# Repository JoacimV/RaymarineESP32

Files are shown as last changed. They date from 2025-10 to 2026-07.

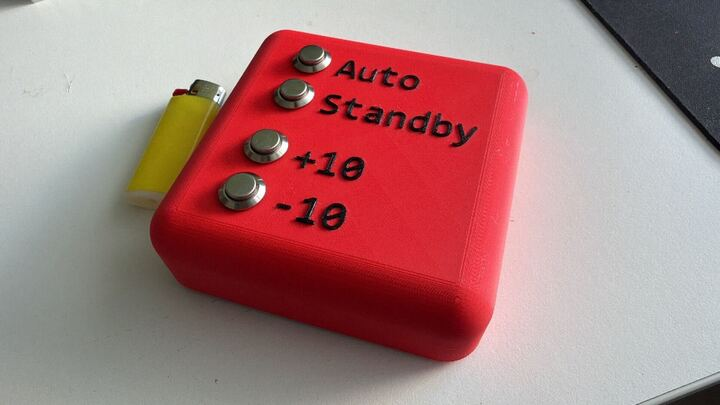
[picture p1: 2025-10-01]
resources/case.png

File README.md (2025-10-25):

### Intro
billede

I wanted an extra way to control my boat's Raymarine autopilot, so I built a simple remote control using an ESP32, MCP2515 CAN Bus module, and some buttons. The remote sends commands to the autopilot over the NMEA2000 network.

The remotes capabilities are basic, but it gets the job done. It has buttons for AUTO, STANDBY, +10 degrees, and -10 degrees. The remote connects to the NMEA2000 network using a MCP2515 CAN Bus module.

This remote costs around 15€ to build, which is significantly cheaper than buying a commercial remote (730€ as of writing this).

The remote connects to the NMEA2000 network, so you need to connect your SeaTalkNG network to your NMEA2000 network, with a NMEA2000 adapter cable.

It currently only works with Raymarine autopilots that support the NMEA2000 protocol, such as the EV-100 and EV-200 series. (I have tested it with EV-100).

### Hardware
- ESP32 + Expansion board - [Amazon affiliate Link](https://amzn.to/46IAd6L)

- MCP2515 CAN Bus Module - [Amazon affiliate Link](https://amzn.to/4nZz4yW)

- Jumper wires [Amazon affiliate Link](https://amzn.to/4pUqzHe)
- DC Cable [Amazon affiliate Link](https://amzn.to/4nsR4Sa)
- NMEA2000 Cable (Cut the female port off) - [Amazon affiliate Link](https://amzn.to/46G0wfn)
- Buttons - [Amazon affiliate Link](https://amzn.to/3IAz6OH)
- Diode WS2812B [Amazon affiliate Link](https://amzn.to/4hwteD4)
- Active Piezo Buzzer [Amazon affiliate Link](https://amzn.to/42XU9lj)

### 3D Printed Case
I designed the case using blender and printed it with BambuLab PLA Matte. You can find the STL files in the `case` directory of this repository.

### Pins

| ESP32 Pin | MCP2515 Pin | Description |
| --- | --- | --- |
| GPIO5 | CS | Chip Select |
| GPIO18 | SCK | Serial Clock |
| GPIO19 | SO | Master In Slave Out |
| GPIO23 | SI | Master Out Slave In |

To power the MCP2515 module, connect the VCC and GND pins to a 5V power on the expansion board.
NMEA2000 power goes to the expansion board through a type b connector.

NMEA white and blue wire go to the MCP2515 module, blue wire to CANL and white wire to CANH.

Wiring for buttons:

| Button  | ESP32 Pin | Description  |
| --- | --- | --- |
| AUTO | GPIO13 | Button Input |
| STANDBY | GPIO12 | Button Input |
| +10 | GPIO14 | Button Input |
| -10 | GPIO26 | Button Input |

Wiring for buzzer:

| Buzzer Pin | ESP32 Pin | Description  |
| --- | --- | --- |
| + | GPIO4 | Buzzer Input |
| GND | GND | Ground |

### Software
This project is built using [PlatformIO](https://platformio.org/).

The raymarine pilot commands are greatly inspired by [this project](https://github.com/matztam/raymarine-evo-pilot-remote).

### Running the Code

## On ESP32
1. Install PlatformIO IDE in Visual Studio Code.
2. Clone this repository to your local machine.
3. Open the project in Visual Studio Code.
4. Connect your ESP32 to your computer via USB.
5. Select the correct board and port in PlatformIO.
6. Click the "Upload" button in PlatformIO to compile and upload the code to your ESP32.

## On your PC
1. Install PlatformIO IDE in Visual Studio Code.
2. Clone this repository to your local machine.
3. Open the project in Visual Studio Code.
4. Open PlatformIO and hit the Build button.
   
### Disclaimer
This project is provided as-is without any warranties. Use it at your own risk. The author is not responsible for any damage or issues that may arise from using this project.

### Libraries
- Timo Lappalainen NMEA2000 library and MCP library: [GitHub Link](https://github.com/ttlappalainen)
- Seeed-Studio CAN library: [GitHub Link](https://github.com/Seeed-Studio/Seeed_Arduino_CAN)

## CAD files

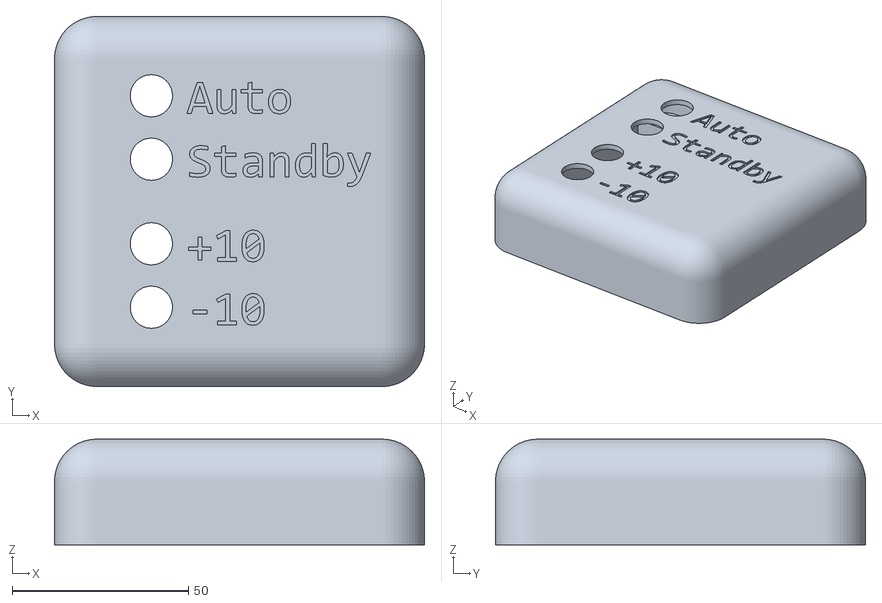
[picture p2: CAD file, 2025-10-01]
resources/case.stl
105.0 x 105.0 x 30.0

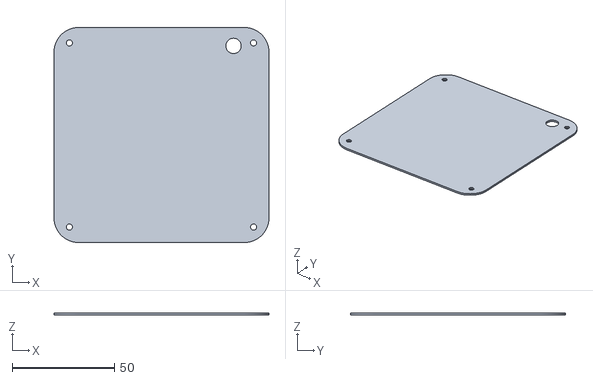
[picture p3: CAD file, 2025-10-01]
resources/lid.stl
105.0 x 105.0 x 1.00

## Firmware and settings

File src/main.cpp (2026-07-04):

#include <Arduino.h>
#include "AutopilotInterface.h"
#include "RaymarinePilot.h"
#include "MessageHandler.h"
#include "BuzzerInterface.h"
#include "PiezoActiveBuzzer.h"
#include "Button2.h"

// Create button instances
Button2 on(14);       // Pin 14 - Auto Mode
Button2 plusTen(12);  // Pin 12 - Starboard 10°
Button2 minusTen(13); // Pin 13 - Port 10°

// Buzzer instance (using interface for flexibility)
BuzzerInterface *buzzer = new PiezoActiveBuzzer(27);

// Global pilot instance (will be initialized in setup())
AutopilotInterface *pilot = nullptr;

void pilotStateUpdateHandler(AutopilotInterface::PilotState state)
{
  if (pilot != nullptr)
  {
    pilot->setObservedState(state);
  }
}

// Handler functions
void onHandler(Button2 &btn)
{
  buzzer->beep();
  AutopilotInterface::PilotState state = pilot->getState();

  // Toggle based on latest bus state; unknown defaults to AUTO.
  if (state == AutopilotInterface::STATE_AUTO)
  {
    pilot->setMode(AutopilotInterface::MODE_STANDBY);
  }
  else
  {
    pilot->setMode(AutopilotInterface::MODE_AUTO);
  }
}

void plusTenHandler(Button2 &btn)
{
  buzzer->beep();
  pilot->turn(AutopilotInterface::TURN_RIGHT_TEN);
}

void minusTenHandler(Button2 &btn)
{
  buzzer->beep();
  pilot->turn(AutopilotInterface::TURN_LEFT_TEN);
}

// Setup function - now AFTER handler definitions
void setup()
{
  Serial.begin(115200);
  Serial.println("Starting Raymarine ESP32 Remote...");

  // Initialize buzzer
  buzzer->begin();

  pilot = new RaymarinePilot();
  if (pilot->isReady())
  {
    Serial.println("✅ Raymarine ESP32 Remote Ready!");
  }
  else
  {
    Serial.println("❌ NMEA2000 failed to initialize");
  }
  MessageHandler::SetPilotStateUpdateCallback(pilotStateUpdateHandler);

  // Setup buttons with handlers
  on.setTapHandler(onHandler);
  plusTen.setTapHandler(plusTenHandler);
  minusTen.setTapHandler(minusTenHandler);
}

void loop()
{
  on.loop();
  plusTen.loop();
  minusTen.loop();
  pilot->update();
  // Small delay to save CPU cycles
  // delay(40);
}

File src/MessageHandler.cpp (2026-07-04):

#include "MessageHandler.h"
#include <Arduino.h>

MessageHandler::PilotStateUpdateCallback MessageHandler::StateUpdateCallback = nullptr;

// Handle incoming NMEA2000 messages
void MessageHandler::HandleNMEA2000Msg(const tN2kMsg &N2kMsg) {
    switch (N2kMsg.PGN) {
        case 65379L:  // Autopilot status
            ParseAutopilotStatus(N2kMsg);
            break;
        // Add more PGN handlers here as needed
        default:
            // Uncomment for debugging unknown messages
            // Serial.print("📡 Unknown PGN: ");
            // Serial.println(N2kMsg.PGN);
            break;
    }
}

void MessageHandler::SetPilotStateUpdateCallback(PilotStateUpdateCallback callback) {
    StateUpdateCallback = callback;
}

// Parse autopilot status message (PGN 65379)
void MessageHandler::ParseAutopilotStatus(const tN2kMsg &N2kMsg) {
    int Index = 2;
    unsigned char Mode = N2kMsg.GetByte(Index);
    unsigned char Submode = N2kMsg.GetByte(Index);

    Serial.print("🚢 PILOT: ");
    if (Mode == 0x00 && Submode == 0x00) {
        if (StateUpdateCallback != nullptr) {
            StateUpdateCallback(AutopilotInterface::STATE_STANDBY);
        }
        Serial.println("STANDBY");
    }
    else if (Mode == 0x40 && Submode == 0x00) {
        if (StateUpdateCallback != nullptr) {
            StateUpdateCallback(AutopilotInterface::STATE_AUTO);
        }
        Serial.println("AUTO");
    }
    else {
        if (StateUpdateCallback != nullptr) {
            StateUpdateCallback(AutopilotInterface::STATE_UNKNOWN);
        }
        Serial.print("Mode=0x");
        Serial.print(Mode, HEX);
        Serial.print(" Sub=0x");
        Serial.println(Submode, HEX);
    }
}

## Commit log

2025-10-01 Add images and models
    [case.stl, lid.stl]
2025-10-01 Move resources to root folder
    [case.stl, lid.stl]
2025-10-25 Add buzzer functionality with PiezoActiveBuzzer implementation and update README
    [main.cpp]
2026-04-23 Remove Button class and implementation; update to use Button2 with new handler setup
2026-05-11 Refactor platformio.ini to comment out unused environment configurations and update esp32-c6-zero settings
2026-05-11 Add pilot state management to AutopilotInterface and MessageHandler
    - Introduced PilotState enum to track the current state of the autopilot.
    - Updated AutopilotInterface with methods to set and get the observed pilot state.
    - Enhanced MessageHandler to handle pilot state updates via a callback mechanism.
    - Modified RaymarinePilot to implement new state management methods.
    - Updated main.cpp to integrate pilot state handling with button actions.
